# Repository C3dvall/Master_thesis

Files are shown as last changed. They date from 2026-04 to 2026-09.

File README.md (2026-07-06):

# IoT Urban Noise Monitoring and Classification

A low cost IoT based urban noise monitoring system developed as part of a Master's Thesis in Computer Science (Internet of Things) at Malmö University.

The project combines embedded machine learning, environmental sensing, and LoRaWAN communication to continuously monitor urban noise levels while classifying the dominant sound source directly on the device.

Instead of transmitting raw audio, the device performs on edge inference and only sends compact metadata consisting of sound level, sound classification, timestamp, and GPS coordinates. This significantly reduces bandwidth usage, improves privacy, and lowers power consumption.

---

## Project Overview

Environmental noise pollution is a growing public health concern. Traditional monitoring stations are expensive and sparsely deployed, making it difficult to understand how noise varies throughout a city.

This project demonstrates a scalable and affordable alternative using low cost hardware and embedded AI.

The system:

- Measures environmental sound pressure levels (dB(A))
- Performs on device sound classification
- Sends results over LoRaWAN
- Stores data for visualization and analysis
- Operates inside a custom weather resistant 3D printed enclosure

The prototype was designed and evaluated for deployment in Malmö, Sweden.

---

## Features

- Real time sound level monitoring
- Embedded machine learning using Edge Impulse
- On device audio classification
- LoRaWAN communication
- GPS location reporting
- Low power operation
- Weather resistant enclosure
- Compact binary payload transmission
- Privacy preserving design by avoiding raw audio transmission

---

## Hardware

The prototype consists of:

| Component | Description |
|---|---|
| Adafruit Feather RP2040 RFM | Main microcontroller with integrated LoRa radio |
| SPH8878LR5H-1 MEMS Microphone | Environmental sound acquisition |
| 868 MHz LoRaWAN Antenna | Extended communication range |
| 3.7V LiPo Battery | Portable power supply |
| Custom 3D Printed Enclosure | Outdoor protection |

---

## System Architecture

The system is divided into three layers:

```
MEMS Microphone
        │
        ▼
Adafruit Feather RP2040
        │
        ├── Measure dB(A)
        ├── Edge Impulse Classification
        └── Package Metadata
                │
                ▼
          LoRaWAN Network
                │
                ▼
      The Things Network (TTN)
                │
                ▼
         MQTT Subscriber
                │
                ▼
        Data Storage / Analysis
```

---

## Machine Learning

The sound classifier was built using Edge Impulse.

### Feature Extraction

- Mel Frequency Energy (MFE)
- 16 kHz sampling
- 2 second inference window
- Embedded classification (Edge Impusle)

### Training Data

The model was trained using a combination of:

- ESC-50
- UrbanSound8K
- Human Screaming Dataset

The final model classifies urban sounds such as:

- Traffic
- Construction
- Human activity
- Alarms

---

## Data Pipeline

1. Capture environmental audio
2. Calculate A weighted sound pressure level
3. Extract MFE features
4. Perform embedded inference
5. Generate classification label
6. Package metadata into binary payload
7. Transmit via LoRaWAN
8. Decode payload on server
9. Store results for later analysis

Only metadata is transmitted.

No raw audio is stored or uploaded.

---

## Payload Structure

| Byte(s) | Content |
|---|---|
| 0 | dB(A) |
| 1 | Hour |
| 2 | Minute |
| 3 | Second |
| 4 | Packet Sequence Number |
| 5–8 | Latitude |
| 9–12 | Longitude |
| 13 | Classification Label |

---

## Technologies Used

- Arduino
- C
- Python
- Edge Impulse
- LoRaWAN
- The Things Network (TTN)
- MQTT
- SolidWorks
- 3D Printing

---

## Evaluation

The prototype was evaluated in several areas:

- MEMS microphone calibration
- dB(A) measurement accuracy
- Acoustic impact of enclosure
- Embedded classification performance
- LoRaWAN transmission reliability
  
---

## Privacy

To improve privacy and reduce network traffic:

- Audio is processed locally.
- Raw recordings are discarded after inference.
- Only classification labels, sound levels, timestamps, and coordinates are transmitted.

---

## Future Improvements

Possible future work includes:

- Solar powered deployment
- Larger scale sensor networks
- Improved battery life
- More robust sound classification
- Additional environmental sensors
- Noise heat map visualization
- Cloud dashboard
- Over the air firmware updates

---

## Thesis

This repository accompanies the Master's Thesis:

**A Low-Cost IoT-Based System for Continuous Urban Noise Classification & Monitoring**

Computer Science – Internet of Things

Malmö University

2026

Authors:

- Christian Edvall
- Peter Ha Zu

Supervisor:

- Ali Soleimani

---

## License

This project is intended for research and educational purposes.

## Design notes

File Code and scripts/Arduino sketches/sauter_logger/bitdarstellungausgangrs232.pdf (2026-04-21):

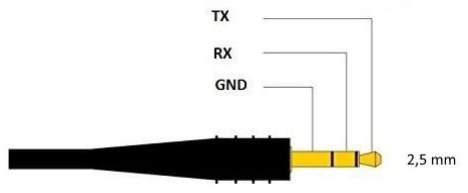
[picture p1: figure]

08.12.2020 | Bitdarstellung Ausgang RS232

1

# SU 130 Interface • Commands and pin out of

# the plug - The SU 130 send continously the 10h as soon as the plug is plugged in - Send the 20h to receive the current data - Transferrate depends on the mode of the device

# SLOW/FAST • SLOW = 1 Sample per second • FAST = 5 Samples per second

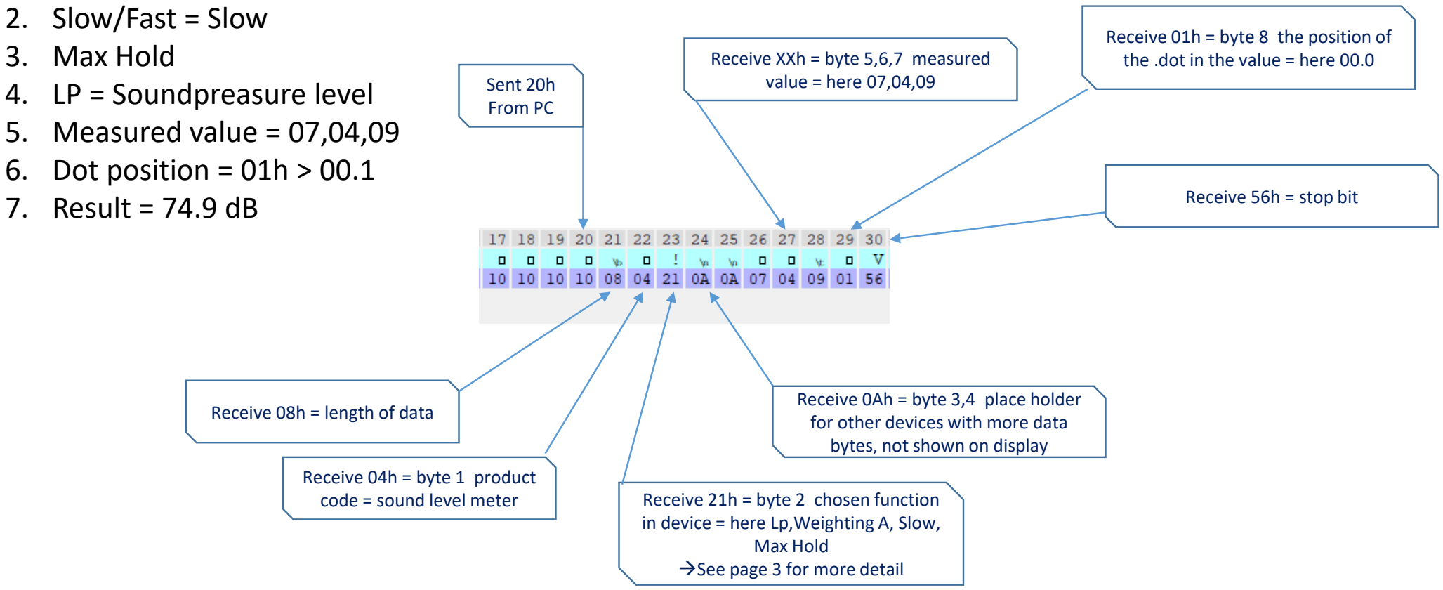
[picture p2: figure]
Sent 20h From PC; Receive 08h = length of data; Receive 04h = byte 1 product; in device = here Lp,Weighting A, Slow, Max Hold →See page 3 for more detail; Receive 0Ah = byte 3,4 place holder for other devices with more data bytes, not shown on display; Receive XXh = byte 5,6,7 measured value = here 07,04,09; Receive 01h = byte 8 the position of the .dot in the value = here 00.0; Receive 56h = stop bit; 2. Slow/Fast = Slow 3. Max Hold 4. LP = Soundpreasure level 5. Measured value = 07,04,09 6. Dot position = 01h > 00.1 7. Result = 74.9 dB

08.12.2020 | Bitdarstellung Ausgang RS232 | 2
code = sound level meter | Receive 21h = byte 2 chosen function

# Values you can generate 1. Weighting =A

1.Byte | | 2.Byte | Measuring mode
MTypeCode | MTypeName | DTypeCode | DTypeName | Unit | Remark
04 | Sound Level Meter | 07 | Real Time Measurement
04 | Sound Level Meter | 08 | Data in Memory
04 | Sound Level Meter | 09
04 | Sound Level Meter | 10 | Lp,Weighting A,Fast | dB
04 | Sound Level Meter | 11 | Lp,Weighting A,Slow | dB
04 | Sound Level Meter | 12 | Lp,Weighting C,Fast | dB
04 | Sound Level Meter | 13 | Lp,Weighting C,Slow | dB
04 | Sound Level Meter | 14 | Lp,Flat,Fast | dB
04 | Sound Level Meter | 15 | Lp,Flat,Slow | dB
04 | Sound Level Meter | 16 | Ln,Weighting A, Fast | %
04 | Sound Level Meter | 17 | Ln,Weighting A, Slow | %
04 | Sound Level Meter | 18 | Leq,Weighting A,Fast,Based on 10s | dB
04 | Sound Level Meter | 19 | Leq,Weighting A,Fast,Based on minutes | dB
04 | Sound Level Meter | 1A | Leq,Weighting A,Slow,Based on 10s | dB
04 | Sound Level Meter | 1B | Leq,Weighting A,Slow,Based on minutes | dB
04 | Sound Level Meter | 1C | CAL, Fast | dB
04 | Sound Level Meter | 1D | CAL, Slow | dB
04 | Sound Level Meter | 20 | Lp,Weighting A,Fast,Max Hold | dB
04 | Sound Level Meter | 21 | Lp,Weighting A,Slow,Max Hold | dB
04 | Sound Level Meter | 22 | Lp,Weighting C,Fast,Max Hold | dB
04 | Sound Level Meter | 23 | Lp,Weighting C,Slow,Max Hold | dB
04 | Sound Level Meter | 24 | Lp,Flat,Fast,Max Hold | dB
04 | Sound Level Meter | 25 | Lp,Flat,Slow,Max Hold | dB
04 | Sound Level Meter | 26 | Ln,Weighting A, Fast,Max Hold | %
04 | Sound Level Meter | 27 | Ln,Weighting A, Slow,Max Hold | %
04 | Sound Level Meter | 28 | Leq,Weighting A,Fast,Based on 10s,Max Hold | dB
04 | Sound Level Meter | 29 | Leq,Weighting A,Fast,Based on minutes,Max Hold | dB
04 | Sound Level Meter | 2A | Leq,Weighting A,Slow,Based on 10s,Max Hold | dB
04 | Sound Level Meter | 2B | Leq,Weighting A,Slow,Based on minutes,Max Hold | dB
04 | Sound Level Meter | 2C | CAL, Fast,Max Hold | dB
04 | Sound Level Meter | 2D | CAL, Slow,Max Hold | dB
08.12.2020 | Bitdarstellung Ausgang RS232 | 3

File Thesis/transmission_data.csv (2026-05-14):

received_at | device_id | f_cnt | dB (A) | Timestamp | seq_number | coordinates | label
2026-05-14T12:54:06.752144183Z | mau-adafruit-01 |  | 77 | 00:00:00 | 0 | 55.60778, 12.99639 | unknown
2026-05-14T12:54:13.412562616Z | mau-adafruit-01 | 1
2026-05-14T12:54:26.764573918Z | mau-adafruit-01 | 2 | 76 | 14:54:24 | 1 | 55.60778, 12.99639 | unknown
2026-05-14T12:54:36.760399956Z | mau-adafruit-01 | 3 | 76 | 14:54:34 | 2 | 55.60778, 12.99639 | industrial
2026-05-14T12:55:06.761819051Z | mau-adafruit-01 | 6 | 76 | 14:55:04 | 5 | 55.60778, 12.99639 | unknown
2026-05-14T12:55:16.760954295Z | mau-adafruit-01 | 7 | 76 | 14:55:14 | 6 | 55.60778, 12.99639 | industrial
2026-05-14T12:55:26.769679082Z | mau-adafruit-01 | 8 | 76 | 14:55:24 | 7 | 55.60778, 12.99639 | unknown
2026-05-14T12:55:36.774386108Z | mau-adafruit-01 | 9 | 76 | 14:55:34 | 8 | 55.60778, 12.99639 | unknown
2026-05-14T12:55:46.762195406Z | mau-adafruit-01 | 10 | 78 | 14:55:44 | 9 | 55.60778, 12.99639 | industrial
2026-05-14T12:55:56.759089401Z | mau-adafruit-01 | 11 | 77 | 14:55:54 | 10 | 55.60778, 12.99639 | unknown
2026-05-14T12:56:06.762947967Z | mau-adafruit-01 | 12 | 85 | 14:56:04 | 11 | 55.60778, 12.99639 | construction
2026-05-14T12:56:16.761220584Z | mau-adafruit-01 | 13 | 77 | 14:56:14 | 12 | 55.60778, 12.99639 | unknown
2026-05-14T12:56:26.757245663Z | mau-adafruit-01 | 14 | 78 | 14:56:24 | 13 | 55.60778, 12.99639 | industrial
2026-05-14T12:56:36.770550971Z | mau-adafruit-01 | 15 | 77 | 14:56:34 | 14 | 55.60778, 12.99639 | unknown
2026-05-14T12:56:46.765741670Z | mau-adafruit-01 | 16 | 78 | 14:56:44 | 15 | 55.60778, 12.99639 | construction
2026-05-14T12:57:06.769222022Z | mau-adafruit-01 | 18 | 77 | 14:57:04 | 17 | 55.60778, 12.99639 | industrial
2026-05-14T12:57:13.412307659Z | mau-adafruit-01 | 19
2026-05-14T12:57:26.765194785Z | mau-adafruit-01 | 20 | 89 | 14:57:24 | 18 | 55.60778, 12.99639 | industrial
2026-05-14T12:57:46.769162473Z | mau-adafruit-01 | 21 | 69 | 14:57:44 | 19 | 55.60778, 12.99639 | industrial
2026-05-14T12:58:06.769857679Z | mau-adafruit-01 | 22 | 68 | 14:58:04 | 20 | 55.60778, 12.99639 | unknown
2026-05-14T12:58:26.772560147Z | mau-adafruit-01 | 23 | 67 | 14:58:24 | 21 | 55.60778, 12.99639 | construction
2026-05-14T12:58:46.764483026Z | mau-adafruit-01 | 24 | 67 | 14:58:44 | 22 | 55.60778, 12.99639 | unknown
2026-05-14T12:59:06.770443761Z | mau-adafruit-01 | 25 | 64 | 14:59:04 | 23 | 55.60778, 12.99639 | unknown
2026-05-14T12:59:13.509791918Z | mau-adafruit-01 | 26
2026-05-14T12:59:26.767130624Z | mau-adafruit-01 | 27 | 64 | 14:59:24 | 24 | 55.60778, 12.99639 | industrial
2026-05-14T12:59:36.762556610Z | mau-adafruit-01 | 28 | 64 | 14:59:34 | 25 | 55.60778, 12.99639 | industrial
2026-05-14T12:59:46.771201635Z | mau-adafruit-01 | 29 | 66 | 14:59:44 | 26 | 55.60778, 12.99639 | unknown
2026-05-14T13:00:06.763825903Z | mau-adafruit-01 | 31 | 71 | 15:00:04 | 28 | 55.60778, 12.99639 | nature
2026-05-14T13:00:16.768351516Z | mau-adafruit-01 | 32 | 65 | 15:00:14 | 29 | 55.60778, 12.99639 | industrial
2026-05-14T13:00:36.764705736Z | mau-adafruit-01 | 34 | 64 | 15:00:34 | 31 | 55.60778, 12.99639 | industrial
2026-05-14T13:00:56.762542090Z | mau-adafruit-01 | 36 | 72 | 15:00:54 | 33 | 55.60778, 12.99639 | industrial
2026-05-14T13:01:16.770124956Z | mau-adafruit-01 | 38 | 64 | 15:01:14 | 35 | 55.60778, 12.99639 | nature
2026-05-14T13:01:26.768653815Z | mau-adafruit-01 | 39 | 63 | 15:01:24 | 36 | 55.60778, 12.99639 | nature
2026-05-14T13:01:46.772285851Z | mau-adafruit-01 | 41 | 67 | 15:01:44 | 37 | 55.60778, 12.99639 | traffic_transport
2026-05-14T13:01:53.435748733Z | mau-adafruit-01 | 42
2026-05-14T13:02:06.769770205Z | mau-adafruit-01 | 43 | 65 | 15:02:04 | 38 | 55.60778, 12.99639 | industrial
2026-05-14T13:02:36.765709924Z | mau-adafruit-01 | 44 | 65 | 15:02:34 | 39 | 55.60778, 12.99639 | unknown
2026-05-14T13:03:06.773082656Z | mau-adafruit-01 | 45 | 63 | 15:03:04 | 40 | 55.60778, 12.99639 | traffic_transport
2026-05-14T13:03:50.112177374Z | mau-adafruit-01 | 46 | 64 | 15:03:34 | 41 | 55.60778, 12.99639 | traffic_transport
2026-05-14T13:03:56.761519327Z | mau-adafruit-01 | 47
2026-05-14T13:04:06.767710046Z | mau-adafruit-01 | 48 | 71 | 15:04:04 | 43 | 55.60778, 12.99639 | construction
2026-05-14T13:04:26.763690297Z | mau-adafruit-01 | 49 | 63 | 15:04:24 | 44 | 55.60778, 12.99639 | unknown
2026-05-14T13:04:53.440796271Z | mau-adafruit-01 | 50 | 75 | 15:04:44 | 45 | 55.60778, 12.99639 | industrial
2026-05-14T13:05:13.446561440Z | mau-adafruit-01 | 51 | 63 | 15:05:04 | 46 | 55.60778, 12.99639 | industrial
2026-05-14T13:05:26.767472501Z | mau-adafruit-01 | 52 | 66 | 15:05:24 | 47 | 55.60778, 12.99639 | industrial
2026-05-14T13:05:46.771626459Z | mau-adafruit-01 | 53 | 64 | 15:05:44 | 48 | 55.60778, 12.99639 | traffic_transport
2026-05-14T13:06:06.768717841Z | mau-adafruit-01 | 54 | 63 | 15:06:04 | 49 | 55.60778, 12.99639 | nature
2026-05-14T13:06:26.772628196Z | mau-adafruit-01 | 55 | 63 | 15:06:24 | 50 | 55.60778, 12.99639 | traffic_transport
2026-05-14T13:06:46.766222533Z | mau-adafruit-01 | 56 | 63 | 15:06:44 | 51 | 55.60778, 12.99639 | unknown
2026-05-14T13:07:46.772624063Z | mau-adafruit-01 | 59 | 63 | 15:07:44 | 54 | 55.60778, 12.99639 | unknown
2026-05-14T13:08:06.768091245Z | mau-adafruit-01 | 60 | 76 | 15:08:04 | 55 | 55.60778, 12.99639 | traffic_transport
2026-05-14T13:09:33.437225452Z | mau-adafruit-01 | 64 | 63 | 15:09:24 | 58 | 55.60778, 12.99639 | traffic_transport
2026-05-14T13:10:03.438837420Z | mau-adafruit-01 | 66 | 63 | 15:09:54 | 59 | 55.60778, 12.99639 | traffic_transport
2026-05-14T13:10:33.455934224Z | mau-adafruit-01 | 67 | 65 | 15:10:24 | 60 | 55.60778, 12.99639 | industrial
2026-05-14T13:11:10.126969790Z | mau-adafruit-01 | 69 | 63 | 15:10:54 | 61 | 55.60778, 12.99639 | industrial
2026-05-14T13:11:26.783694319Z | mau-adafruit-01 | 71 | 66 | 15:11:24 | 63 | 55.60778, 12.99639 | nature
2026-05-14T13:11:46.775559539Z | mau-adafruit-01 | 73 | 69 | 15:11:44 | 64 | 55.60778, 12.99639 | industrial
2026-05-14T13:11:53.424446747Z | mau-adafruit-01 | 74
2026-05-14T13:12:20.118108438Z | mau-adafruit-01 | 75 | 64 | 15:12:04 | 65 | 55.60778, 12.99639 | industrial
2026-05-14T13:12:43.439985635Z | mau-adafruit-01 | 76 | 64 | 15:12:34 | 66 | 55.60778, 12.99639 | industrial
2026-05-14T13:13:06.766256773Z | mau-adafruit-01 | 77 | 72 | 15:13:04 | 67 | 55.60778, 12.99639 | unknown
2026-05-14T13:15:13.419717368Z | mau-adafruit-01 | 82
2026-05-14T13:15:33.438535625Z | mau-adafruit-01 | 83 | 75 | 15:15:24 | 72 | 55.60778, 12.99639 | traffic_transport
2026-05-14T13:15:46.775126510Z | mau-adafruit-01 | 84 | 77 | 15:15:44 | 73 | 55.60778, 12.99639 | construction
2026-05-14T13:16:26.774663965Z | mau-adafruit-01 | 86 | 83 | 15:16:24 | 75 | 55.60778, 12.99639 | unknown
2026-05-14T13:16:46.766614369Z | mau-adafruit-01 | 87 | 82 | 15:16:44 | 76 | 55.60778, 12.99639 | industrial
2026-05-14T13:17:26.769482653Z | mau-adafruit-01 | 89 | 75 | 15:17:24 | 78 | 55.60778, 12.99639 | industrial
2026-05-14T13:17:46.769640361Z | mau-adafruit-01 | 90 | 73 | 15:17:44 | 79 | 55.60778, 12.99639 | industrial
2026-05-14T13:19:06.774812752Z | mau-adafruit-01 | 94 | 71 | 15:19:04 | 83 | 55.60778, 12.99639 | unknown
2026-05-14T13:19:26.819306645Z | mau-adafruit-01 | 96 | 70 | 15:19:24 | 84 | 55.60778, 12.99639 | industrial
2026-05-14T13:19:46.779308216Z | mau-adafruit-01 | 98 | 73 | 15:19:44 | 85 | 55.60778, 12.99639 | industrial
2026-05-14T13:19:53.550388475Z | mau-adafruit-01 | 99
2026-05-14T13:20:20.120896057Z | mau-adafruit-01 | 100 | 69 | 15:20:04 | 86 | 55.60778, 12.99639 | industrial
2026-05-14T13:20:36.772763328Z | mau-adafruit-01 | 101 | 65 | 15:20:34 | 87 | 55.60778, 12.99639 | traffic_transport
2026-05-14T13:21:13.449703836Z | mau-adafruit-01 | 102 | 63 | 15:21:04 | 88 | 55.60778, 12.99639 | industrial
2026-05-14T13:21:36.791468124Z | mau-adafruit-01 | 103 | 66 | 15:21:34 | 89 | 55.60778, 12.99639 | industrial
2026-05-14T13:22:06.770516605Z | mau-adafruit-01 | 104 | 65 | 15:22:04 | 90 | 55.60778, 12.99639 | traffic_transport
2026-05-14T13:22:46.777394927Z | mau-adafruit-01 | 107 | 64 | 15:22:44 | 92 | 55.60778, 12.99639 | industrial
2026-05-14T13:23:06.767559651Z | mau-adafruit-01 | 108 | 64 | 15:23:04 | 93 | 55.60778, 12.99639 | industrial
2026-05-14T13:23:26.771141874Z | mau-adafruit-01 | 109 | 71 | 15:23:24 | 94 | 55.60778, 12.99639 | unknown
2026-05-14T13:23:53.453400986Z | mau-adafruit-01 | 110 | 78 | 15:23:44 | 95 | 55.60778, 12.99639 | nature
2026-05-14T13:24:06.776980474Z | mau-adafruit-01 | 111 | 70 | 15:24:04 | 96 | 55.60778, 12.99639 | traffic_transport
2026-05-14T13:24:26.774028818Z | mau-adafruit-01 | 112 | 68 | 15:24:24 | 97 | 55.60778, 12.99639 | construction

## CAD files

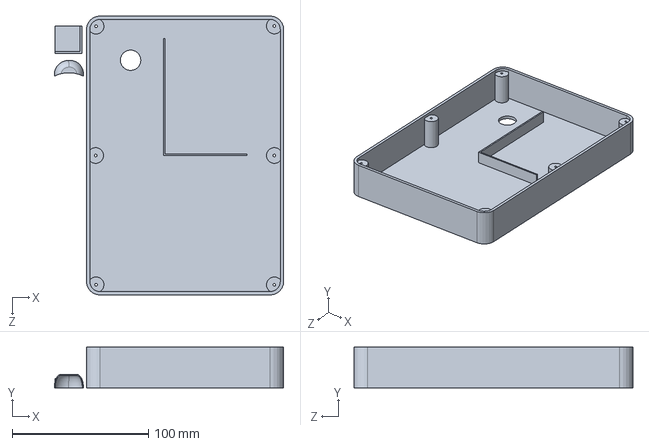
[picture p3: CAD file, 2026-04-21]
Enclosure design/casing_front_prototype.SLDPRT
168.6 x 30.0 x 205.0 mm

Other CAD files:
Enclosure design/casing_front_prototype.3mf
Enclosure design/casing_front_prototype.STL

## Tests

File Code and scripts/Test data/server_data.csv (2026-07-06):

received_at | device_id | dev_eui | dev_addr | f_cnt | f_port | frm_payload_base64 | frm_payload_hex | frequency_hz | spreading_factor | bandwidth | coding_rate | rssi | snr | gateway_id | consumed_airtime_s
2026-04-20T12:19:07.685078454Z | mau-adafruit-01 | 70B3D57ED0076D00 | 260BF200 | 39 | 1 | Qg0AAQsDUIHkAMZPJgE= | 420d00010b035081e400c64f2601 | 868500000 | 7 | 125000 | 4/5 | -101 | 6.5 | openlogger-mlm-city | 0.066816
2026-04-20T12:19:14.332652755Z | mau-adafruit-01 | 70B3D57ED0076D00 | 260BF200 | 40 |  |  |  | 867700000 | 7 | 125000 | 4/5 | -101 | 8 | openlogger-mlm-city | 0.046336
2026-04-20T12:19:50.453011702Z | mau-adafruit-01 | 70B3D57ED0076D00 | 260BF200 | 41 | 1 | Qg0AAQsDUIHkAMZPJgE= | 420d00010b035081e400c64f2601 | 868100000 | 7 | 125000 | 4/5 | -108 | 6 | openlogger-mlm-city | 0.066816
2026-04-20T12:20:39.911194197Z | mau-adafruit-01 | 70B3D57ED0076D00 | 260BF200 | 42 | 1 | Qg0AAQsDUIHkAMZPJgE= | 420d00010b035081e400c64f2601 | 868300000 | 7 | 125000 | 4/5 | -113 | -0.5 | openlogger-mlm-city | 0.066816
2026-04-20T12:21:29.375481300Z | mau-adafruit-01 | 70B3D57ED0076D00 | 260BF200 | 43 | 1 | Qg0AAQsDUIHkAMZPJgE= | 420d00010b035081e400c64f2601 | 867300000 | 7 | 125000 | 4/5 | -102 | 7.8 | openlogger-mlm-city | 0.066816
2026-05-14T12:54:06.752144183Z | mau-adafruit-01 | 70B3D57ED0076D00 | 260BE2AB |  | 1 | TQAAAAADUIHkAMZPJgA= | 4d00000000035081e400c64f2600 | 868100000 | 7 | 125000 | 4/5 | -102 | 8.8 | openlogger-mlm-city | 0.066816
2026-05-14T12:54:13.412562616Z | mau-adafruit-01 | 70B3D57ED0076D00 | 260BE2AB | 1 |  |  |  | 868300000 | 7 | 125000 | 4/5 | -102 |  | openlogger-mlm-city | 0.046336
2026-05-14T12:54:26.764573918Z | mau-adafruit-01 | 70B3D57ED0076D00 | 260BE2AB | 2 | 1 | TA42GAEDUIHkAMZPJgA= | 4c0e361801035081e400c64f2600 | 867300000 | 7 | 125000 | 4/5 | -101 | 7.8 | openlogger-mlm-city | 0.066816
2026-05-14T12:54:36.760399956Z | mau-adafruit-01 | 70B3D57ED0076D00 | 260BE2AB | 3 | 1 | TA42IgIDUIHkAMZPJgQ= | 4c0e362202035081e400c64f2604 | 867100000 | 7 | 125000 | 4/5 | -103 | 8.8 | openlogger-mlm-city | 0.066816
2026-05-14T12:54:56.800599802Z | mau-adafruit-01 | 70B3D57ED0076D00 | 260BE2AB | 5 | 1 | TQ42NgQDUIHkAMZPJgA= | 4d0e363604035081e400c64f2600 | 867900000 | 7 | 125000 | 4/5 | -102 | 9.3 | openlogger-mlm-city | 0.066816
2026-05-14T12:55:06.761819051Z | mau-adafruit-01 | 70B3D57ED0076D00 | 260BE2AB | 6 | 1 | TA43BAUDUIHkAMZPJgA= | 4c0e370405035081e400c64f2600 | 868500000 | 7 | 125000 | 4/5 | -102 | 4 | openlogger-mlm-city | 0.066816
2026-05-14T12:55:16.760954295Z | mau-adafruit-01 | 70B3D57ED0076D00 | 260BE2AB | 7 | 1 | TA43DgYDUIHkAMZPJgQ= | 4c0e370e06035081e400c64f2604 | 868100000 | 7 | 125000 | 4/5 | -102 | 8 | openlogger-mlm-city | 0.066816
2026-05-14T12:55:26.769679082Z | mau-adafruit-01 | 70B3D57ED0076D00 | 260BE2AB | 8 | 1 | TA43GAcDUIHkAMZPJgA= | 4c0e371807035081e400c64f2600 | 867700000 | 7 | 125000 | 4/5 | -98 | 2.5 | openlogger-mlm-city | 0.066816
2026-05-14T12:55:36.774386108Z | mau-adafruit-01 | 70B3D57ED0076D00 | 260BE2AB | 9 | 1 | TA43IggDUIHkAMZPJgA= | 4c0e372208035081e400c64f2600 | 868300000 | 7 | 125000 | 4/5 | -97 | 3 | openlogger-mlm-city | 0.066816
2026-05-14T12:55:46.762195406Z | mau-adafruit-01 | 70B3D57ED0076D00 | 260BE2AB | 10 | 1 | Tg43LAkDUIHkAMZPJgQ= | 4e0e372c09035081e400c64f2604 | 867700000 | 7 | 125000 | 4/5 | -101 | 9.3 | openlogger-mlm-city | 0.066816
2026-05-14T12:55:56.759089401Z | mau-adafruit-01 | 70B3D57ED0076D00 | 260BE2AB | 11 | 1 | TQ43NgoDUIHkAMZPJgA= | 4d0e37360a035081e400c64f2600 | 868100000 | 7 | 125000 | 4/5 | -102 | 7 | openlogger-mlm-city | 0.066816
2026-05-14T12:56:06.762947967Z | mau-adafruit-01 | 70B3D57ED0076D00 | 260BE2AB | 12 | 1 | VQ44BAsDUIHkAMZPJgI= | 550e38040b035081e400c64f2602 | 868500000 | 7 | 125000 | 4/5 | -103 | 7 | openlogger-mlm-city | 0.066816
2026-05-14T12:56:16.761220584Z | mau-adafruit-01 | 70B3D57ED0076D00 | 260BE2AB | 13 | 1 | TQ44DgwDUIHkAMZPJgA= | 4d0e380e0c035081e400c64f2600 | 867100000 | 7 | 125000 | 4/5 | -99 | 8.3 | openlogger-mlm-city | 0.066816
2026-05-14T12:56:26.757245663Z | mau-adafruit-01 | 70B3D57ED0076D00 | 260BE2AB | 14 | 1 | Tg44GA0DUIHkAMZPJgQ= | 4e0e38180d035081e400c64f2604 | 868300000 | 7 | 125000 | 4/5 | -103 | 6.5 | openlogger-mlm-city | 0.066816
2026-05-14T12:56:36.770550971Z | mau-adafruit-01 | 70B3D57ED0076D00 | 260BE2AB | 15 | 1 | TQ44Ig4DUIHkAMZPJgA= | 4d0e38220e035081e400c64f2600 | 867900000 | 7 | 125000 | 4/5 | -107 | 8.8 | openlogger-mlm-city | 0.066816
2026-05-14T12:56:46.765741670Z | mau-adafruit-01 | 70B3D57ED0076D00 | 260BE2AB | 16 | 1 | Tg44LA8DUIHkAMZPJgI= | 4e0e382c0f035081e400c64f2602 | 867300000 | 7 | 125000 | 4/5 | -101 | 8.3 | openlogger-mlm-city | 0.066816
2026-05-14T12:57:06.769222022Z | mau-adafruit-01 | 70B3D57ED0076D00 | 260BE2AB | 18 | 1 | TQ45BBEDUIHkAMZPJgQ= | 4d0e390411035081e400c64f2604 | 867700000 | 7 | 125000 | 4/5 | -100 | 9.3 | openlogger-mlm-city | 0.066816
2026-05-14T12:57:13.412307659Z | mau-adafruit-01 | 70B3D57ED0076D00 | 260BE2AB | 19 |  |  |  | 868300000 | 7 | 125000 | 4/5 | -102 | 5 | openlogger-mlm-city | 0.046336
2026-05-14T12:57:26.765194785Z | mau-adafruit-01 | 70B3D57ED0076D00 | 260BE2AB | 20 | 1 | WQ45GBIDUIHkAMZPJgQ= | 590e391812035081e400c64f2604 | 868500000 | 7 | 125000 | 4/5 | -103 | 5.5 | openlogger-mlm-city | 0.066816
2026-05-14T12:57:46.769162473Z | mau-adafruit-01 | 70B3D57ED0076D00 | 260BE2AB | 21 | 1 | RQ45LBMDUIHkAMZPJgQ= | 450e392c13035081e400c64f2604 | 867100000 | 7 | 125000 | 4/5 | -102 | 8.5 | openlogger-mlm-city | 0.066816
2026-05-14T12:58:06.769857679Z | mau-adafruit-01 | 70B3D57ED0076D00 | 260BE2AB | 22 | 1 | RA46BBQDUIHkAMZPJgA= | 440e3a0414035081e400c64f2600 | 867900000 | 7 | 125000 | 4/5 | -105 | 7.8 | openlogger-mlm-city | 0.066816
2026-05-14T12:58:26.772560147Z | mau-adafruit-01 | 70B3D57ED0076D00 | 260BE2AB | 23 | 1 | Qw46GBUDUIHkAMZPJgI= | 430e3a1815035081e400c64f2602 | 868100000 | 7 | 125000 | 4/5 | -113 | 5.5 | openlogger-mlm-city | 0.066816
2026-05-14T12:58:46.764483026Z | mau-adafruit-01 | 70B3D57ED0076D00 | 260BE2AB | 24 | 1 | Qw46LBYDUIHkAMZPJgA= | 430e3a2c16035081e400c64f2600 | 868500000 | 7 | 125000 | 4/5 | -113 | -1.3 | openlogger-mlm-city | 0.066816
2026-05-14T12:59:06.770443761Z | mau-adafruit-01 | 70B3D57ED0076D00 | 260BE2AB | 25 | 1 | QA47BBcDUIHkAMZPJgA= | 400e3b0417035081e400c64f2600 | 867900000 | 7 | 125000 | 4/5 | -112 | 5 | openlogger-mlm-city | 0.066816
2026-05-14T12:59:13.509791918Z | mau-adafruit-01 | 70B3D57ED0076D00 | 260BE2AB | 26 |  |  |  | 868300000 | 7 | 125000 | 4/5 | -109 | -3.3 | openlogger-mlm-city | 0.046336
2026-05-14T12:59:26.767130624Z | mau-adafruit-01 | 70B3D57ED0076D00 | 260BE2AB | 27 | 1 | QA47GBgDUIHkAMZPJgQ= | 400e3b1818035081e400c64f2604 | 867700000 | 7 | 125000 | 4/5 | -108 |  | openlogger-mlm-city | 0.066816
2026-05-14T12:59:36.762556610Z | mau-adafruit-01 | 70B3D57ED0076D00 | 260BE2AB | 28 | 1 | QA47IhkDUIHkAMZPJgQ= | 400e3b2219035081e400c64f2604 | 867300000 | 7 | 125000 | 4/5 | -108 | 5.5 | openlogger-mlm-city | 0.066816
2026-05-14T12:59:46.771201635Z | mau-adafruit-01 | 70B3D57ED0076D00 | 260BE2AB | 29 | 1 | Qg47LBoDUIHkAMZPJgA= | 420e3b2c1a035081e400c64f2600 | 867900000 | 7 | 125000 | 4/5 | -111 | 5.8 | openlogger-mlm-city | 0.066816
2026-05-14T13:00:06.763825903Z | mau-adafruit-01 | 70B3D57ED0076D00 | 260BE2AB | 31 | 1 | Rw8ABBwDUIHkAMZPJgM= | 470f00041c035081e400c64f2603 | 867300000 | 7 | 125000 | 4/5 | -108 | 2.3 | openlogger-mlm-city | 0.066816
2026-05-14T13:00:16.768351516Z | mau-adafruit-01 | 70B3D57ED0076D00 | 260BE2AB | 32 | 1 | QQ8ADh0DUIHkAMZPJgQ= | 410f000e1d035081e400c64f2604 | 868300000 | 7 | 125000 | 4/5 | -111 | 5.5 | openlogger-mlm-city | 0.066816
2026-05-14T13:00:36.764705736Z | mau-adafruit-01 | 70B3D57ED0076D00 | 260BE2AB | 34 | 1 | QA8AIh8DUIHkAMZPJgQ= | 400f00221f035081e400c64f2604 | 868500000 | 7 | 125000 | 4/5 | -107 | 3.5 | openlogger-mlm-city | 0.066816
2026-05-14T13:00:56.762542090Z | mau-adafruit-01 | 70B3D57ED0076D00 | 260BE2AB | 36 | 1 | SA8ANiEDUIHkAMZPJgQ= | 480f003621035081e400c64f2604 | 867100000 | 7 | 125000 | 4/5 | -114 | 0.8 | openlogger-mlm-city | 0.066816
2026-05-14T13:01:16.770124956Z | mau-adafruit-01 | 70B3D57ED0076D00 | 260BE2AB | 38 | 1 | QA8BDiMDUIHkAMZPJgM= | 400f010e23035081e400c64f2603 | 868500000 | 7 | 125000 | 4/5 | -107 | 2 | openlogger-mlm-city | 0.066816
2026-05-14T13:01:26.768653815Z | mau-adafruit-01 | 70B3D57ED0076D00 | 260BE2AB | 39 | 1 | Pw8BGCQDUIHkAMZPJgM= | 3f0f011824035081e400c64f2603 | 867700000 | 7 | 125000 | 4/5 | -107 | -2.5 | openlogger-mlm-city | 0.066816
2026-05-14T13:01:46.772285851Z | mau-adafruit-01 | 70B3D57ED0076D00 | 260BE2AB | 41 | 1 | Qw8BLCUDUIHkAMZPJgE= | 430f012c25035081e400c64f2601 | 867100000 | 7 | 125000 | 4/5 | -111 | 5.3 | openlogger-mlm-city | 0.066816
2026-05-14T13:01:53.435748733Z | mau-adafruit-01 | 70B3D57ED0076D00 | 260BE2AB | 42 |  |  |  | 867300000 | 7 | 125000 | 4/5 | -111 | 5.5 | openlogger-mlm-city | 0.046336
2026-05-14T13:02:06.769770205Z | mau-adafruit-01 | 70B3D57ED0076D00 | 260BE2AB | 43 | 1 | QQ8CBCYDUIHkAMZPJgQ= | 410f020426035081e400c64f2604 | 867900000 | 7 | 125000 | 4/5 | -108 | 4.3 | openlogger-mlm-city | 0.066816
2026-05-14T13:02:36.765709924Z | mau-adafruit-01 | 70B3D57ED0076D00 | 260BE2AB | 44 | 1 | QQ8CIicDUIHkAMZPJgA= | 410f022227035081e400c64f2600 | 868100000 | 7 | 125000 | 4/5 | -113 | 0.3 | openlogger-mlm-city | 0.066816
2026-05-14T13:03:06.773082656Z | mau-adafruit-01 | 70B3D57ED0076D00 | 260BE2AB | 45 | 1 | Pw8DBCgDUIHkAMZPJgE= | 3f0f030428035081e400c64f2601 | 867100000 | 7 | 125000 | 4/5 | -111 | 6.3 | openlogger-mlm-city | 0.066816
2026-05-14T13:03:50.112177374Z | mau-adafruit-01 | 70B3D57ED0076D00 | 260BE2AB | 46 | 1 | QA8DIikDUIHkAMZPJgE= | 400f032229035081e400c64f2601 | 868500000 | 7 | 125000 | 4/5 | -104 | 0.5 | openlogger-mlm-city | 0.066816
2026-05-14T13:03:56.761519327Z | mau-adafruit-01 | 70B3D57ED0076D00 | 260BE2AB | 47 |  |  |  | 867900000 | 7 | 125000 | 4/5 | -112 | 4 | openlogger-mlm-city | 0.046336
2026-05-14T13:04:06.767710046Z | mau-adafruit-01 | 70B3D57ED0076D00 | 260BE2AB | 48 | 1 | Rw8EBCsDUIHkAMZPJgI= | 470f04042b035081e400c64f2602 | 867100000 | 7 | 125000 | 4/5 | -112 | 1 | openlogger-mlm-city | 0.066816
2026-05-14T13:04:26.763690297Z | mau-adafruit-01 | 70B3D57ED0076D00 | 260BE2AB | 49 | 1 | Pw8EGCwDUIHkAMZPJgA= | 3f0f04182c035081e400c64f2600 | 868300000 | 7 | 125000 | 4/5 | -113 | 0.8 | openlogger-mlm-city | 0.066816
2026-05-14T13:04:53.440796271Z | mau-adafruit-01 | 70B3D57ED0076D00 | 260BE2AB | 50 | 1 | Sw8ELC0DUIHkAMZPJgQ= | 4b0f042c2d035081e400c64f2604 | 868300000 | 7 | 125000 | 4/5 | -114 | -1.3 | openlogger-mlm-city | 0.066816
2026-05-14T13:05:13.446561440Z | mau-adafruit-01 | 70B3D57ED0076D00 | 260BE2AB | 51 | 1 | Pw8FBC4DUIHkAMZPJgQ= | 3f0f05042e035081e400c64f2604 | 867100000 | 7 | 125000 | 4/5 | -115 | 0.5 | openlogger-mlm-city | 0.066816
2026-05-14T13:05:26.767472501Z | mau-adafruit-01 | 70B3D57ED0076D00 | 260BE2AB | 52 | 1 | Qg8FGC8DUIHkAMZPJgQ= | 420f05182f035081e400c64f2604 | 868100000 | 7 | 125000 | 4/5 | -114 | -6.5 | openlogger-mlm-city | 0.066816
2026-05-14T13:05:46.771626459Z | mau-adafruit-01 | 70B3D57ED0076D00 | 260BE2AB | 53 | 1 | QA8FLDADUIHkAMZPJgE= | 400f052c30035081e400c64f2601 | 867900000 | 7 | 125000 | 4/5 | -115 | 2.3 | openlogger-mlm-city | 0.066816
2026-05-14T13:06:06.768717841Z | mau-adafruit-01 | 70B3D57ED0076D00 | 260BE2AB | 54 | 1 | Pw8GBDEDUIHkAMZPJgM= | 3f0f060431035081e400c64f2603 | 867700000 | 7 | 125000 | 4/5 | -115 | 0.3 | openlogger-mlm-city | 0.066816
2026-05-14T13:06:26.772628196Z | mau-adafruit-01 | 70B3D57ED0076D00 | 260BE2AB | 55 | 1 | Pw8GGDIDUIHkAMZPJgE= | 3f0f061832035081e400c64f2601 | 868100000 | 7 | 125000 | 4/5 | -117 | -0.3 | openlogger-mlm-city | 0.066816
2026-05-14T13:06:46.766222533Z | mau-adafruit-01 | 70B3D57ED0076D00 | 260BE2AB | 56 | 1 | Pw8GLDMDUIHkAMZPJgA= | 3f0f062c33035081e400c64f2600 | 867300000 | 7 | 125000 | 4/5 | -114 | -3 | openlogger-mlm-city | 0.066816
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

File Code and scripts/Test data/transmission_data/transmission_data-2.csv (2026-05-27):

received_at | device_id | f_cnt | dB (A) | Timestamp | seq_number | coordinates | label
2026-05-27T13:12:08.466619843Z | mau-adafruit-01 | 2 | 74 | 15:12:06 | 2 | 55.60778, 12.99639 | industrial
2026-05-27T13:12:18.467777652Z | mau-adafruit-01 | 3 | 77 | 15:12:16 | 3 | 55.60778, 12.99639 | industrial
2026-05-27T13:12:28.467538348Z | mau-adafruit-01 | 4 | 76 | 15:12:26 | 4 | 55.60778, 12.99639 | industrial
2026-05-27T13:12:38.454808074Z | mau-adafruit-01 | 5 | 79 | 15:12:36 | 5 | 55.60778, 12.99639 | industrial
2026-05-27T13:12:48.460193081Z | mau-adafruit-01 | 6 | 89 | 15:12:46 | 6 | 55.60778, 12.99639 | industrial
2026-05-27T13:13:08.460589269Z | mau-adafruit-01 | 8 | 85 | 15:13:06 | 8 | 55.60778, 12.99639 | industrial
2026-05-27T13:13:18.460940630Z | mau-adafruit-01 | 9 | 67 | 15:13:16 | 9 | 55.60778, 12.99639 | nature
2026-05-27T13:13:38.464675122Z | mau-adafruit-01 | 11 | 65 | 15:13:36 | 11 | 55.60778, 12.99639 | unknown
2026-05-27T13:13:45.110676178Z | mau-adafruit-01 | 12
2026-05-27T13:13:58.460443143Z | mau-adafruit-01 | 13 | 66 | 15:13:56 | 12 | 55.60778, 12.99639 | traffic_transport
2026-05-27T13:14:18.466914553Z | mau-adafruit-01 | 14 | 65 | 15:14:16 | 13 | 55.60778, 12.99639 | nature
2026-05-27T13:14:45.136808575Z | mau-adafruit-01 | 15 | 70 | 15:14:36 | 14 | 55.60778, 12.99639 | unknown
2026-05-27T13:14:58.460818213Z | mau-adafruit-01 | 16 | 83 | 15:14:56 | 15 | 55.60778, 12.99639 | industrial
2026-05-27T13:15:25.134880193Z | mau-adafruit-01 | 17 | 75 | 15:15:16 | 16 | 55.60778, 12.99639 | construction
2026-05-27T13:15:45.246131438Z | mau-adafruit-01 | 18 | 72 | 15:15:36 | 17 | 55.60778, 12.99639 | industrial
2026-05-27T13:15:58.462863475Z | mau-adafruit-01 | 19 | 64 | 15:15:56 | 18 | 55.60778, 12.99639 | nature
2026-05-27T13:16:05.109885991Z | mau-adafruit-01 | 20
2026-05-27T13:16:18.460218856Z | mau-adafruit-01 | 21 | 63 | 15:16:16 | 19 | 55.60778, 12.99639 | unknown
2026-05-27T13:16:28.481432255Z | mau-adafruit-01 | 22 | 68 | 15:16:26 | 20 | 55.60778, 12.99639 | unknown
2026-05-27T13:16:38.456387730Z | mau-adafruit-01 | 23 | 68 | 15:16:36 | 21 | 55.60778, 12.99639 | industrial
2026-05-27T13:16:48.467582885Z | mau-adafruit-01 | 24 | 67 | 15:16:46 | 22 | 55.60778, 12.99639 | unknown
2026-05-27T13:16:58.458677753Z | mau-adafruit-01 | 25 | 67 | 15:16:56 | 23 | 55.60778, 12.99639 | unknown
2026-05-27T13:17:08.469667528Z | mau-adafruit-01 | 26 | 64 | 15:17:06 | 24 | 55.60778, 12.99639 | unknown
2026-05-27T13:17:28.462848540Z | mau-adafruit-01 | 28 | 65 | 15:17:26 | 26 | 55.60778, 12.99639 | unknown
2026-05-27T13:17:48.457615016Z | mau-adafruit-01 | 30 | 66 | 15:17:46 | 28 | 55.60778, 12.99639 | construction
2026-05-27T13:17:58.471357772Z | mau-adafruit-01 | 31 | 68 | 15:17:56 | 29 | 55.60778, 12.99639 | nature
2026-05-27T13:18:05.114171719Z | mau-adafruit-01 | 32
2026-05-27T13:18:18.458159492Z | mau-adafruit-01 | 33 | 66 | 15:18:16 | 30 | 55.60778, 12.99639 | nature
2026-05-27T13:18:45.159286259Z | mau-adafruit-01 | 34 | 66 | 15:18:36 | 31 | 55.60778, 12.99639 | unknown
2026-05-27T13:18:58.467019127Z | mau-adafruit-01 | 35 | 65 | 15:18:56 | 32 | 55.60778, 12.99639 | nature
2026-05-27T13:19:18.487900307Z | mau-adafruit-01 | 36 | 76 | 15:19:16 | 33 | 55.60778, 12.99639 | industrial
2026-05-27T13:19:38.467366584Z | mau-adafruit-01 | 37 | 70 | 15:19:36 | 34 | 55.60778, 12.99639 | industrial
2026-05-27T13:19:58.460080296Z | mau-adafruit-01 | 38 | 70 | 15:19:56 | 35 | 55.60778, 12.99639 | industrial
2026-05-27T13:20:05.119134965Z | mau-adafruit-01 | 39
2026-05-27T13:20:18.469061138Z | mau-adafruit-01 | 40 | 71 | 15:20:16 | 36 | 55.60778, 12.99639 | unknown
2026-05-27T13:20:28.461275379Z | mau-adafruit-01 | 41 | 66 | 15:20:26 | 37 | 55.60778, 12.99639 | industrial
2026-05-27T13:20:48.468360825Z | mau-adafruit-01 | 43 | 63 | 15:20:46 | 39 | 55.60778, 12.99639 | industrial
2026-05-27T13:21:18.457895645Z | mau-adafruit-01 | 46 | 65 | 15:21:16 | 42 | 55.60778, 12.99639 | nature
2026-05-27T13:21:28.466727845Z | mau-adafruit-01 | 47 | 65 | 15:21:26 | 43 | 55.60778, 12.99639 | nature
2026-05-27T13:22:08.461900986Z | mau-adafruit-01 | 51 | 76 | 15:22:06 | 47 | 55.60778, 12.99639 | industrial
2026-05-27T13:22:18.464413941Z | mau-adafruit-01 | 52 | 77 | 15:22:16 | 48 | 55.60778, 12.99639 | unknown
2026-05-27T13:22:28.469006997Z | mau-adafruit-01 | 53 | 64 | 15:22:26 | 49 | 55.60778, 12.99639 | unknown
2026-05-27T13:22:38.463097312Z | mau-adafruit-01 | 54 | 69 | 15:22:36 | 50 | 55.60778, 12.99639 | industrial
2026-05-27T13:23:18.469765865Z | mau-adafruit-01 | 58 | 69 | 15:23:16 | 54 | 55.60778, 12.99639 | nature
2026-05-27T13:23:25.115431934Z | mau-adafruit-01 | 59
2026-05-27T13:23:45.137953576Z | mau-adafruit-01 | 60 | 72 | 15:23:36 | 55 | 55.60778, 12.99639 | industrial
2026-05-27T13:24:21.807512204Z | mau-adafruit-01 | 61 | 96 | 15:24:06 | 56 | 55.60778, 12.99639 | industrial
2026-05-27T13:24:38.463317076Z | mau-adafruit-01 | 62 | 88 | 15:24:36 | 57 | 55.60778, 12.99639 | industrial
2026-05-27T13:25:15.140019314Z | mau-adafruit-01 | 63 | 76 | 15:25:06 | 58 | 55.60778, 12.99639 | unknown
2026-05-27T13:25:38.468284073Z | mau-adafruit-01 | 64 | 93 | 15:25:36 | 59 | 55.60778, 12.99639 | industrial
2026-05-27T13:26:08.460535727Z | mau-adafruit-01 | 65 | 78 | 15:26:06 | 60 | 55.60778, 12.99639 | industrial
2026-05-27T13:26:45.141380730Z | mau-adafruit-01 | 67 | 84 | 15:26:36 | 62 | 55.60778, 12.99639 | industrial
2026-05-27T13:26:58.518386743Z | mau-adafruit-01 | 68 | 71 | 15:26:56 | 63 | 55.60778, 12.99639 | unknown
2026-05-27T13:27:18.469186327Z | mau-adafruit-01 | 69 | 73 | 15:27:16 | 64 | 55.60778, 12.99639 | industrial
2026-05-27T13:27:38.471896903Z | mau-adafruit-01 | 70 | 69 | 15:27:36 | 65 | 55.60778, 12.99639 | industrial
2026-05-27T13:28:05.139675905Z | mau-adafruit-01 | 71 | 69 | 15:27:56 | 66 | 55.60778, 12.99639 | nature
2026-05-27T13:28:18.466532236Z | mau-adafruit-01 | 72 | 64 | 15:28:16 | 67 | 55.60778, 12.99639 | industrial
2026-05-27T13:28:38.461510993Z | mau-adafruit-01 | 73 | 70 | 15:28:36 | 68 | 55.60778, 12.99639 | unknown
2026-05-27T13:28:58.468271745Z | mau-adafruit-01 | 74 | 67 | 15:28:56 | 69 | 55.60778, 12.99639 | nature
2026-05-27T13:29:18.534367779Z | mau-adafruit-01 | 75 | 75 | 15:29:16 | 70 | 55.60778, 12.99639 | nature
2026-05-27T13:29:45.144562553Z | mau-adafruit-01 | 76 | 69 | 15:29:36 | 71 | 55.60778, 12.99639 | industrial
2026-05-27T13:29:58.471266650Z | mau-adafruit-01 | 77 | 75 | 15:29:56 | 72 | 55.60778, 12.99639 | industrial
2026-05-27T13:30:18.470752885Z | mau-adafruit-01 | 78 | 65 | 15:30:16 | 73 | 55.60778, 12.99639 | nature
2026-05-27T13:30:38.471244485Z | mau-adafruit-01 | 79 | 76 | 15:30:36 | 74 | 55.60778, 12.99639 | industrial
2026-05-27T13:30:45.133396904Z | mau-adafruit-01 | 80
2026-05-27T13:30:58.470622928Z | mau-adafruit-01 | 81 | 75 | 15:30:56 | 75 | 55.60778, 12.99639 | industrial
2026-05-27T13:31:18.465127912Z | mau-adafruit-01 | 82 | 77 | 15:31:16 | 76 | 55.60778, 12.99639 | nature
2026-05-27T13:31:38.472257925Z | mau-adafruit-01 | 83 | 77 | 15:31:36 | 77 | 55.60778, 12.99639 | unknown
2026-05-27T13:31:58.466175158Z | mau-adafruit-01 | 84 | 67 | 15:31:56 | 78 | 55.60778, 12.99639 | industrial
2026-05-27T13:32:18.466999410Z | mau-adafruit-01 | 85 | 66 | 15:32:16 | 79 | 55.60778, 12.99639 | unknown

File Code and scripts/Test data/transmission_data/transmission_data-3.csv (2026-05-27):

received_at | device_id | f_cnt | dB (A) | Timestamp | seq_number | coordinates | label
2026-05-27T13:41:39.870777231Z | mau-adafruit-01 | 9 | 71 | 15:41:37 | 9 | 55.60778, 12.99639 | construction
2026-05-27T13:41:59.876731449Z | mau-adafruit-01 | 11 | 67 | 15:41:57 | 11 | 55.60778, 12.99639 | unknown
2026-05-27T13:42:06.530783333Z | mau-adafruit-01 | 12
2026-05-27T13:42:19.870939649Z | mau-adafruit-01 | 13 | 74 | 15:42:17 | 12 | 55.60778, 12.99639 | unknown
2026-05-27T13:42:39.876747848Z | mau-adafruit-01 | 14 | 73 | 15:42:37 | 13 | 55.60778, 12.99639 | industrial
2026-05-27T13:42:59.910500597Z | mau-adafruit-01 | 15 | 76 | 15:42:57 | 14 | 55.60778, 12.99639 | unknown
2026-05-27T13:43:19.875017306Z | mau-adafruit-01 | 16 | 69 | 15:43:17 | 15 | 55.60778, 12.99639 | unknown
2026-05-27T13:43:39.880787845Z | mau-adafruit-01 | 17 | 70 | 15:43:37 | 16 | 55.60778, 12.99639 | unknown
2026-05-27T13:44:06.549041271Z | mau-adafruit-01 | 18 | 72 | 15:43:57 | 17 | 55.60778, 12.99639 | unknown
2026-05-27T13:44:20.097129973Z | mau-adafruit-01 | 19 | 89 | 15:44:17 | 18 | 55.60778, 12.99639 | industrial
2026-05-27T13:44:26.535293510Z | mau-adafruit-01 | 20
2026-05-27T13:44:39.872791024Z | mau-adafruit-01 | 21 | 79 | 15:44:37 | 19 | 55.60778, 12.99639 | industrial
2026-05-27T13:44:59.884652034Z | mau-adafruit-01 | 23 | 73 | 15:44:57 | 21 | 55.60778, 12.99639 | unknown
2026-05-27T13:45:09.879919785Z | mau-adafruit-01 | 24 | 82 | 15:45:07 | 22 | 55.60778, 12.99639 | industrial
2026-05-27T13:45:19.884472577Z | mau-adafruit-01 | 25 | 83 | 15:45:17 | 23 | 55.60778, 12.99639 | industrial
2026-05-27T13:45:29.878268118Z | mau-adafruit-01 | 26 | 79 | 15:45:27 | 24 | 55.60778, 12.99639 | industrial
2026-05-27T13:45:39.871993643Z | mau-adafruit-01 | 27 | 81 | 15:45:37 | 25 | 55.60778, 12.99639 | industrial
2026-05-27T13:45:49.955085068Z | mau-adafruit-01 | 28 | 86 | 15:45:47 | 26 | 55.60778, 12.99639 | industrial
2026-05-27T13:45:59.878943293Z | mau-adafruit-01 | 29 | 77 | 15:45:57 | 27 | 55.60778, 12.99639 | industrial
2026-05-27T13:46:09.878604182Z | mau-adafruit-01 | 30 | 72 | 15:46:07 | 28 | 55.60778, 12.99639 | industrial
2026-05-27T13:46:29.874509617Z | mau-adafruit-01 | 32 | 77 | 15:46:27 | 30 | 55.60778, 12.99639 | industrial
2026-05-27T13:46:36.528920640Z | mau-adafruit-01 | 33
2026-05-27T13:46:49.883841522Z | mau-adafruit-01 | 34 | 67 | 15:46:47 | 31 | 55.60778, 12.99639 | unknown
2026-05-27T13:47:09.874668318Z | mau-adafruit-01 | 35 | 71 | 15:47:07 | 32 | 55.60778, 12.99639 | unknown
2026-05-27T13:47:30.016088587Z | mau-adafruit-01 | 36 | 90 | 15:47:27 | 33 | 55.60778, 12.99639 | industrial
2026-05-27T13:47:49.873875984Z | mau-adafruit-01 | 37 | 68 | 15:47:47 | 34 | 55.60778, 12.99639 | unknown
2026-05-27T13:48:09.884961303Z | mau-adafruit-01 | 38 | 98 | 15:48:07 | 35 | 55.60778, 12.99639 | industrial
2026-05-27T13:48:23.554790803Z | mau-adafruit-01 | 39
2026-05-27T13:48:39.901832685Z | mau-adafruit-01 | 40 | 77 | 15:48:37 | 36 | 55.60778, 12.99639 | industrial
2026-05-27T13:48:50.388872380Z | mau-adafruit-01 | 41 | 69 | 15:48:47 | 37 | 55.60778, 12.99639 | unknown
2026-05-27T13:48:59.879053609Z | mau-adafruit-01 | 42 | 66 | 15:48:57 | 38 | 55.60778, 12.99639 | unknown
2026-05-27T13:49:09.877634143Z | mau-adafruit-01 | 43 | 67 | 15:49:07 | 39 | 55.60778, 12.99639 | unknown
2026-05-27T13:49:19.884711849Z | mau-adafruit-01 | 44 | 73 | 15:49:17 | 40 | 55.60778, 12.99639 | unknown
2026-05-27T13:49:29.887457162Z | mau-adafruit-01 | 45 | 66 | 15:49:27 | 41 | 55.60778, 12.99639 | unknown
2026-05-27T13:49:39.874990141Z | mau-adafruit-01 | 46 | 66 | 15:49:37 | 42 | 55.60778, 12.99639 | unknown
2026-05-27T13:49:49.882014446Z | mau-adafruit-01 | 47 | 68 | 15:49:47 | 43 | 55.60778, 12.99639 | unknown
2026-05-27T13:49:59.879258628Z | mau-adafruit-01 | 48 | 67 | 15:49:57 | 44 | 55.60778, 12.99639 | unknown
2026-05-27T13:50:10.098840301Z | mau-adafruit-01 | 49 | 72 | 15:50:07 | 45 | 55.60778, 12.99639 | unknown
2026-05-27T13:50:19.882991482Z | mau-adafruit-01 | 50 | 70 | 15:50:17 | 46 | 55.60778, 12.99639 | industrial
2026-05-27T13:50:29.880779867Z | mau-adafruit-01 | 51 | 75 | 15:50:27 | 47 | 55.60778, 12.99639 | industrial
2026-05-27T13:50:39.936854829Z | mau-adafruit-01 | 52 | 71 | 15:50:37 | 48 | 55.60778, 12.99639 | unknown
2026-05-27T13:50:49.907081918Z | mau-adafruit-01 | 53 | 67 | 15:50:47 | 49 | 55.60778, 12.99639 | unknown
2026-05-27T13:50:59.938474579Z | mau-adafruit-01 | 54 | 66 | 15:50:57 | 50 | 55.60778, 12.99639 | unknown
2026-05-27T13:51:09.884722845Z | mau-adafruit-01 | 55 | 73 | 15:51:07 | 51 | 55.60778, 12.99639 | unknown
2026-05-27T13:51:19.887347459Z | mau-adafruit-01 | 56 | 71 | 15:51:17 | 52 | 55.60778, 12.99639 | unknown
2026-05-27T13:51:29.883088655Z | mau-adafruit-01 | 57 | 68 | 15:51:27 | 53 | 55.60778, 12.99639 | unknown
2026-05-27T13:51:39.885029801Z | mau-adafruit-01 | 58 | 72 | 15:51:37 | 54 | 55.60778, 12.99639 | unknown
2026-05-27T13:51:49.936589668Z | mau-adafruit-01 | 59 | 71 | 15:51:47 | 55 | 55.60778, 12.99639 | industrial
2026-05-27T13:51:56.523987266Z | mau-adafruit-01 | 60
2026-05-27T13:52:09.884695562Z | mau-adafruit-01 | 61 | 75 | 15:52:07 | 56 | 55.60778, 12.99639 | industrial
2026-05-27T13:52:29.899703578Z | mau-adafruit-01 | 63 | 74 | 15:52:27 | 58 | 55.60778, 12.99639 | construction
2026-05-27T13:52:39.875010094Z | mau-adafruit-01 | 64 | 78 | 15:52:37 | 59 | 55.60778, 12.99639 | unknown
2026-05-27T13:52:49.878580845Z | mau-adafruit-01 | 65 | 74 | 15:52:47 | 60 | 55.60778, 12.99639 | industrial
2026-05-27T13:52:59.909776601Z | mau-adafruit-01 | 66 | 68 | 15:52:57 | 61 | 55.60778, 12.99639 | industrial
2026-05-27T13:53:09.878622381Z | mau-adafruit-01 | 67 | 69 | 15:53:07 | 62 | 55.60778, 12.99639 | unknown
2026-05-27T13:53:29.881150790Z | mau-adafruit-01 | 69 | 70 | 15:53:27 | 64 | 55.60778, 12.99639 | unknown
2026-05-27T13:53:39.887911988Z | mau-adafruit-01 | 70 | 70 | 15:53:37 | 65 | 55.60778, 12.99639 | unknown
2026-05-27T13:53:49.875233839Z | mau-adafruit-01 | 71 | 71 | 15:53:47 | 66 | 55.60778, 12.99639 | industrial
2026-05-27T13:53:56.586912853Z | mau-adafruit-01 | 72
2026-05-27T13:54:09.885123081Z | mau-adafruit-01 | 73 | 65 | 15:54:07 | 67 | 55.60778, 12.99639 | nature
2026-05-27T13:54:29.884775557Z | mau-adafruit-01 | 74 | 72 | 15:54:27 | 68 | 55.60778, 12.99639 | unknown
2026-05-27T13:54:49.880241927Z | mau-adafruit-01 | 75 | 67 | 15:54:47 | 69 | 55.60778, 12.99639 | unknown
2026-05-27T13:55:09.877243714Z | mau-adafruit-01 | 76 | 70 | 15:55:07 | 70 | 55.60778, 12.99639 | industrial
2026-05-27T13:55:36.557350953Z | mau-adafruit-01 | 77 | 67 | 15:55:27 | 71 | 55.60778, 12.99639 | unknown
2026-05-27T13:55:49.885237138Z | mau-adafruit-01 | 78 | 67 | 15:55:47 | 72 | 55.60778, 12.99639 | unknown
2026-05-27T13:56:09.877523248Z | mau-adafruit-01 | 79 | 75 | 15:56:07 | 73 | 55.60778, 12.99639 | industrial
2026-05-27T13:56:16.587983525Z | mau-adafruit-01 | 80
2026-05-27T13:56:29.877874623Z | mau-adafruit-01 | 81 | 76 | 15:56:27 | 74 | 55.60778, 12.99639 | industrial
2026-05-27T13:56:39.960781750Z | mau-adafruit-01 | 82 | 71 | 15:56:37 | 75 | 55.60778, 12.99639 | unknown
2026-05-27T13:56:49.878461918Z | mau-adafruit-01 | 83 | 65 | 15:56:47 | 76 | 55.60778, 12.99639 | unknown
2026-05-27T13:56:59.880615546Z | mau-adafruit-01 | 84 | 70 | 15:56:57 | 77 | 55.60778, 12.99639 | industrial
2026-05-27T13:57:10.063204902Z | mau-adafruit-01 | 85 | 69 | 15:57:07 | 78 | 55.60778, 12.99639 | unknown
2026-05-27T13:57:19.887174593Z | mau-adafruit-01 | 86 | 68 | 15:57:17 | 79 | 55.60778, 12.99639 | unknown
2026-05-27T13:57:29.879254313Z | mau-adafruit-01 | 87 | 73 | 15:57:27 | 80 | 55.60778, 12.99639 | unknown
2026-05-27T13:57:49.887078752Z | mau-adafruit-01 | 89 | 68 | 15:57:47 | 82 | 55.60778, 12.99639 | unknown
2026-05-27T13:57:59.924772587Z | mau-adafruit-01 | 90 | 73 | 15:57:57 | 83 | 55.60778, 12.99639 | industrial
2026-05-27T13:58:10.006033700Z | mau-adafruit-01 | 91 | 67 | 15:58:07 | 84 | 55.60778, 12.99639 | unknown
2026-05-27T13:58:29.880773652Z | mau-adafruit-01 | 93 | 67 | 15:58:27 | 86 | 55.60778, 12.99639 | unknown
2026-05-27T13:58:36.536401816Z | mau-adafruit-01 | 94
2026-05-27T13:58:49.887298210Z | mau-adafruit-01 | 95 | 70 | 15:58:47 | 87 | 55.60778, 12.99639 | unknown
2026-05-27T13:59:09.885090675Z | mau-adafruit-01 | 96 | 81 | 15:59:07 | 88 | 55.60778, 12.99639 | unknown
2026-05-27T13:59:29.886846066Z | mau-adafruit-01 | 97 | 70 | 15:59:27 | 89 | 55.60778, 12.99639 | unknown
2026-05-27T13:59:49.950945653Z | mau-adafruit-01 | 98 | 70 | 15:59:47 | 90 | 55.60778, 12.99639 | unknown
2026-05-27T14:00:09.877649320Z | mau-adafruit-01 | 99 | 69 | 16:00:07 | 91 | 55.60778, 12.99639 | unknown
2026-05-27T14:00:23.381896844Z | mau-adafruit-01 | 100
2026-05-27T14:00:39.889097841Z | mau-adafruit-01 | 101 | 69 | 16:00:37 | 92 | 55.60778, 12.99639 | industrial
2026-05-27T14:00:49.909416520Z | mau-adafruit-01 | 102 | 69 | 16:00:47 | 93 | 55.60778, 12.99639 | unknown
2026-05-27T14:01:09.885318723Z | mau-adafruit-01 | 104 | 68 | 16:01:07 | 95 | 55.60778, 12.99639 | nature
2026-05-27T14:01:19.880853558Z | mau-adafruit-01 | 105 | 67 | 16:01:17 | 96 | 55.60778, 12.99639 | unknown
2026-05-27T14:01:29.889195753Z | mau-adafruit-01 | 106 | 66 | 16:01:27 | 97 | 55.60778, 12.99639 | unknown
2026-05-27T14:01:39.882609959Z | mau-adafruit-01 | 107 | 64 | 16:01:37 | 98 | 55.60778, 12.99639 | unknown
2026-05-27T14:01:59.876605627Z | mau-adafruit-01 | 109 | 67 | 16:01:57 | 100 | 55.60778, 12.99639 | unknown
2026-05-27T14:02:09.966085459Z | mau-adafruit-01 | 110 | 69 | 16:02:07 | 101 | 55.60778, 12.99639 | unknown
2026-05-27T14:02:20.234100366Z | mau-adafruit-01 | 111 | 68 | 16:02:17 | 102 | 55.60778, 12.99639 | unknown
2026-05-27T14:02:26.537402482Z | mau-adafruit-01 | 112
2026-05-27T14:02:39.940489680Z | mau-adafruit-01 | 113 | 72 | 16:02:37 | 103 | 55.60778, 12.99639 | unknown

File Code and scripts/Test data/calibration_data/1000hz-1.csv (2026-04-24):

sauter_timestamp | sauter_dba | mems_timestamp | mems_dba
2026-04-24T16:54:23.361744 | 62.0 | 2026-04-24T16:54:22.936 | 29.04
2026-04-24T16:54:24.004752 | 62.0 | 2026-04-24T16:54:23.936 | 29.0
2026-04-24T16:54:24.630222 | 62.0 | 2026-04-24T16:54:24.936 | 28.98
2026-04-24T16:54:25.271480 | 62.2 | 2026-04-24T16:54:25.436 | 28.99
2026-04-24T16:54:25.910751 | 62.3 | 2026-04-24T16:54:26.436 | 28.98
2026-04-24T16:54:26.561856 | 62.2 | 2026-04-24T16:54:27.436 | 28.99
2026-04-24T16:54:27.191961 | 62.3 | 2026-04-24T16:54:28.436 | 28.95
2026-04-24T16:54:27.832379 | 62.3 | 2026-04-24T16:54:28.936 | 28.94
2026-04-24T16:54:28.472625 | 62.4 | 2026-04-24T16:54:29.936 | 29.04
2026-04-24T16:54:29.121483 | 62.4 | 2026-04-24T16:54:30.436 | 29.0
2026-04-24T16:54:29.758808 | 62.3 | 2026-04-24T16:54:30.936 | 28.97
2026-04-24T16:54:30.400324 | 62.3 | 2026-04-24T16:54:31.436 | 28.91
2026-04-24T16:54:31.038799 | 62.3 | 2026-04-24T16:54:32.436 | 28.71
2026-04-24T16:54:31.683348 | 62.3 | 2026-04-24T16:54:32.936 | 28.79
2026-04-24T16:54:32.316189 | 62.4 | 2026-04-24T16:54:33.436 | 28.78
2026-04-24T16:54:32.957722 | 62.3 | 2026-04-24T16:54:34.436 | 28.75
2026-04-24T16:54:33.587536 | 62.2 | 2026-04-24T16:54:34.936 | 28.95
2026-04-24T16:54:34.232367 | 59.9 | 2026-04-24T16:54:35.436 | 28.88
2026-04-24T16:54:34.877612 | 62.8 | 2026-04-24T16:54:35.936 | 28.92
2026-04-24T16:54:35.522087 | 63.4 | 2026-04-24T16:54:36.936 | 28.92
2026-04-24T16:54:36.157452 | 63.4 | 2026-04-24T16:54:37.436 | 28.98

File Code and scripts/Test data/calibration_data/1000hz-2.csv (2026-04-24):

sauter_timestamp | sauter_dba | mems_timestamp | mems_dba
2026-04-24T16:54:00.313776 | 62.7 | 2026-04-24T16:53:59.689 | 28.84
2026-04-24T16:54:00.961729 | 62.6 | 2026-04-24T16:54:00.689 | 28.83
2026-04-24T16:54:01.594722 | 62.7 | 2026-04-24T16:54:01.189 | 28.91
2026-04-24T16:54:02.245046 | 63.1 | 2026-04-24T16:54:02.189 | 28.72
2026-04-24T16:54:02.884834 | 63.1 | 2026-04-24T16:54:03.189 | 28.77
2026-04-24T16:54:03.513930 | 63.1 | 2026-04-24T16:54:04.189 | 28.86
2026-04-24T16:54:04.160921 | 63.1 | 2026-04-24T16:54:04.689 | 28.84
2026-04-24T16:54:04.794889 | 63.1 | 2026-04-24T16:54:05.689 | 28.91
2026-04-24T16:54:05.445340 | 63.1 | 2026-04-24T16:54:06.689 | 28.84
2026-04-24T16:54:06.079775 | 63.2 | 2026-04-24T16:54:07.189 | 28.84
2026-04-24T16:54:06.720445 | 63.1 | 2026-04-24T16:54:08.189 | 28.9
2026-04-24T16:54:07.352176 | 63.1 | 2026-04-24T16:54:08.689 | 28.85
2026-04-24T16:54:07.993787 | 63.0 | 2026-04-24T16:54:09.189 | 28.84
2026-04-24T16:54:08.643356 | 62.9 | 2026-04-24T16:54:09.689 | 28.73
2026-04-24T16:54:09.276429 | 60.8 | 2026-04-24T16:54:10.689 | 28.88
2026-04-24T16:54:09.919520 | 61.8 | 2026-04-24T16:54:11.189 | 28.89
2026-04-24T16:54:10.561381 | 62.7 | 2026-04-24T16:54:11.689 | 28.78
2026-04-24T16:54:11.205599 | 63.9 | 2026-04-24T16:54:12.189 | 28.85
2026-04-24T16:54:11.845737 | 63.9 | 2026-04-24T16:54:13.189 | 28.93
2026-04-24T16:54:12.474217 | 63.9 | 2026-04-24T16:54:13.689 | 28.93
2026-04-24T16:54:13.114174 | 63.9 | 2026-04-24T16:54:14.189 | 28.92
2026-04-24T16:54:13.745024 | 63.8 | 2026-04-24T16:54:15.189 | 28.93

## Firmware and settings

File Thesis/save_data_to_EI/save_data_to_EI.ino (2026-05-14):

#include <Arduino.h>
#include "hardware/adc.h"
#include "hardware/dma.h"
#include "hardware/irq.h"

// ===== USER CONFIG =====
#define MIC_PIN        A0
#define SAMPLE_RATE    16000
#define RECORD_SECONDS 5
#define TOTAL_SAMPLES  (SAMPLE_RATE * RECORD_SECONDS)

// ===== GLOBALS =====
int16_t *audioBuffer;
int dma_chan;
volatile bool dma_done = false;

// ===== DMA IRQ HANDLER =====
void dma_handler() {
    dma_hw->ints0 = 1u << dma_chan;
    dma_done = true;
}

// ===== MICROPHONE SELF TEST =====
bool testMic() {
    Serial.println("[TEST] Checking microphone...");

    long sum = 0;

    for (int i = 0; i < 200; i++) {
        int v = analogRead(MIC_PIN);
        sum += v;
        delay(2);
    }

    int avg = sum / 200;

    Serial.printf("[TEST] Mic average level: %d\n", avg);

    if (avg < 200 || avg > 4000) {
        Serial.println("[ERROR] Mic reading out of expected range");
        return false;
    }

    Serial.println("[TEST] Microphone OK");
    return true;
}

// ===== SEND EDGE IMPULSE HEADER =====
void sendEIHeader() {

    Serial.println(
        "{\"protected\":{\"ver\":\"v1\"},"
        "\"payload\":{"
        "\"device_name\":\"rp2040-mic\","
        "\"device_type\":\"custom\","
        "\"interval_ms\":0.0625,"
        "\"sensors\":[{\"name\":\"audio\",\"units\":\"raw\"}]"
        "}}"
    );
}

// ===== SETUP ADC + DMA =====
void setupADC_DMA() {

    adc_init();
    adc_gpio_init(MIC_PIN);
    adc_select_input(0);

    dma_chan = dma_claim_unused_channel(true);

    dma_channel_config cfg = dma_channel_get_default_config(dma_chan);

    channel_config_set_transfer_data_size(&cfg, DMA_SIZE_16);
    channel_config_set_read_increment(&cfg, false);
    channel_config_set_write_increment(&cfg, true);
    channel_config_set_dreq(&cfg, DREQ_ADC);

    dma_channel_configure(
        dma_chan,
        &cfg,
        audioBuffer,
        &adc_hw->fifo,
        TOTAL_SAMPLES,
        false
    );

    adc_fifo_setup(
        true,
        true,
        1,
        false,
        false
    );

    adc_set_clkdiv(48000000.0 / SAMPLE_RATE);

    dma_channel_set_irq0_enabled(dma_chan, true);

    irq_set_exclusive_handler(DMA_IRQ_0, dma_handler);
    irq_set_enabled(DMA_IRQ_0, true);
}

// ===== RECORD AUDIO =====
void recordAudio() {

    dma_done = false;

    dma_channel_set_write_addr(
        dma_chan,
        audioBuffer,
        false
    );

    dma_channel_set_trans_count(
        dma_chan,
        TOTAL_SAMPLES,
        false
    );

    adc_run(true);

    dma_channel_start(dma_chan);

    while (!dma_done) {
    }

    adc_run(false);

    adc_fifo_drain();
}

// ===== STREAM TO EDGE IMPULSE =====
void streamToEI() {

    for (int i = 0; i < TOTAL_SAMPLES; i++) {

        Serial.println(audioBuffer[i]);
    }
}

// ===== SETUP =====
void setup() {

    Serial.begin(115200);

    delay(2000);

    Serial.println("\n=== Continuous RP2040 Audio Stream ===");

    audioBuffer = (int16_t*) malloc(
        TOTAL_SAMPLES * sizeof(int16_t)
    );

    if (!audioBuffer) {

        Serial.println("[FATAL] Failed to allocate buffer");

        while (true) {
            delay(1000);
        }
    }

    if (!testMic()) {

        while (true) {
            delay(1000);
        }
    }

    setupADC_DMA();

    sendEIHeader();

    Serial.println("[INFO] Continuous streaming started");
}

// ===== MAIN LOOP =====
void loop() {

    recordAudio();

    streamToEI();
}

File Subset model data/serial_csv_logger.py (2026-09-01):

#!/usr/bin/env python3
"""
serial_csv_logger.py

Companion script for device_firmware_standalone.ino.

The board cannot write a .csv file by itself (no SD card / filesystem on this
build), so this script runs on your computer, listens to the serial port, and
appends every classification result the board prints to a real .csv file.

Usage:
    pip install pyserial
    python serial_csv_logger.py --port COM4 --baud 115200 --out construction.csv

On Windows, --port will look like "COM5" instead of "/dev/ttyACM0".
On macOS, it usually looks like "/dev/cu.usbmodemXXXX".

Behavior:
    - Only lines from the board prefixed with "CSV:" are treated as data rows.
    - The "CSV_HEADER:" line the board sends once at boot is used to write
      the column header into the .csv file the first time it's seen.
    - Everything else (the human-readable [INF]/[DB] log lines) is printed
      to your terminal for visibility, but NOT written to the .csv file.
    - The script appends, so you can stop/restart it without losing data.
    - A wall-clock timestamp is added as an extra column so you have a real
      date/time even though the board itself only knows millis() or a
      compile-time clock.
"""

import argparse
import csv
import datetime
import sys
import time

try:
    import serial
except ImportError:
    print("This script requires pyserial. Install it with:\n    pip install pyserial")
    sys.exit(1)


def main():
    parser = argparse.ArgumentParser(description="Log Edge Impulse classification CSV lines from serial to a .csv file.")
    parser.add_argument("--port", required=True, help="Serial port, e.g. /dev/ttyACM0 or COM5")
    parser.add_argument("--baud", type=int, default=115200, help="Baud rate (default: 115200, must match Serial.begin in the sketch)")
    parser.add_argument("--out", default="classifications.csv", help="Output CSV file path (default: classifications.csv)")
    args = parser.parse_args()

    header_written = False
    board_header_fields = None

    print(f"Opening {args.port} @ {args.baud} baud...")
    try:
        ser = serial.Serial(args.port, args.baud, timeout=1)
    except serial.SerialException as e:
        print(f"Could not open serial port: {e}")
        sys.exit(1)

    # Give the board a moment after the port opens (many boards reset on connect)
    time.sleep(2)

    # Open in append mode so repeated runs don't overwrite previous data
    csv_file = open(args.out, "a", newline="")
    writer = csv.writer(csv_file)

    print(f"Logging classification rows to {args.out}")
    print("Press Ctrl+C to stop.\n")

    try:
        while True:
            raw = ser.readline()
            if not raw:
                continue

            try:
                line = raw.decode("utf-8", errors="replace").strip()
            except Exception:
                continue

            if not line:
                continue

            if line.startswith("CSV_HEADER:"):
                board_header_fields = line[len("CSV_HEADER:"):].split(",")
                if not header_written:
                    writer.writerow(["timestamp"] + board_header_fields)
                    csv_file.flush()
                    header_written = True
                print(f"[header] {line}")
                continue

            if line.startswith("CSV:"):
                fields = line[len("CSV:"):].split(",")
                timestamp = datetime.datetime.now().isoformat(timespec="seconds")

                if not header_written:
                    # Fallback header if the board's header line was missed
                    fallback = ["seq", "millis", "hour", "minute", "second", "db_level", "category", "confidence"]
                    writer.writerow(["timestamp"] + fallback[: len(fields)])
                    header_written = True

                writer.writerow([timestamp] + fields)
                csv_file.flush()
                print(f"[logged] {timestamp},{line[len('CSV:'):]}")
                continue

            # Anything else is just the board's human-readable log — show it,
            # don't write it to the CSV.
            print(f"[board] {line}")

    except KeyboardInterrupt:
        print("\nStopping — closing serial port and CSV file.")
    finally:
        ser.close()
        csv_file.close()


if __name__ == "__main__":
    main()

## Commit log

2026-04-24 Calibration data
    [1000hz-1.csv, 1000hz-2.csv, 2000hz-1.csv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]
2026-04-24 remove old data
    [1000hz-1.csv, 1000hz-2.csv, 2000hz-1.csv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]
2026-04-24 calibration data and logs
    [1000hz-1.csv, 1000hz-2.csv, 2000hz-1.csv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]
2026-04-30 Upated filenames on chainsaw files
2026-04-30 changed filenames for jackhammer and drilling
2026-05-06 rock drill relabel
2026-05-06 Sorted chainsaw_presence
2026-05-06 hoe-ram & pile-driver sorted
2026-05-09 addded more samples to aircraft
2026-05-11 Added sound retention lohs
    [mems_2026-05-11T12-09-36.csv, mems_2026-05-11T12-10-01.csv, mems_2026-05-11T12-10-20.csv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]
2026-05-11 added more samples
2026-05-11 more samples
2026-05-14 transmission data
    [raw_data.csv, transmission_data.csv]
2026-05-27 Transmission result data
    [raw_data.csv, transmission_data-2.csv, transmission_data-3.csv]
2026-07-03 Subset model testing data
    [bastardburgers.csv, espressohouse.csv, latinskolan.csv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]
2026-07-06 reorganized repository
    [1000hz-1.csv, 1000hz-2.csv, 2000hz-1.csv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]
2026-09-01 subset model data - construction
    [construction.csv, sum.xlsx]
2026-09-02 fixed subset model data
    [construction.csv, sum.csv]
2026-09-02 fixed sum.csv
    [construction (2).csv, sum.csv]
